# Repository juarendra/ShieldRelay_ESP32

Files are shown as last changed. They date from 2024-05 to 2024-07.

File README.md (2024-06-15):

# ShieldRelay_ESP32
Relay Shield for ESP32 , Nodemcu V2 Amica or Nodemcu V3 Lolin. In board there are 5 Relay and 3 type of Relay, first is 30A Relay Coil, second is 10 A Relay Coil and third is SSR 2A. And there are full extend header of Microcontroller. the power using Stepdown LM2596 with output 5V 3A and Input 5-30VDC. 

## Spesification ShieldRelay_ESP32
- Input Power 5-30VDC and stepdown to 5VDC
- PTC Fuse
- INPUT HEADER
- VCC HEADER
- VCC Selector 3v3 or 5V
- Supported ESP32 DEV KIT, NODEMCU V2 or V3
- Pin Header GPIO with Servo Formated
- 1 x 30A Relay Coil
- 2 x 10A Relay Couil
- 2 x 2A SSR

# Privew Hardware ShieldRelay_ESP32
<p align="center">
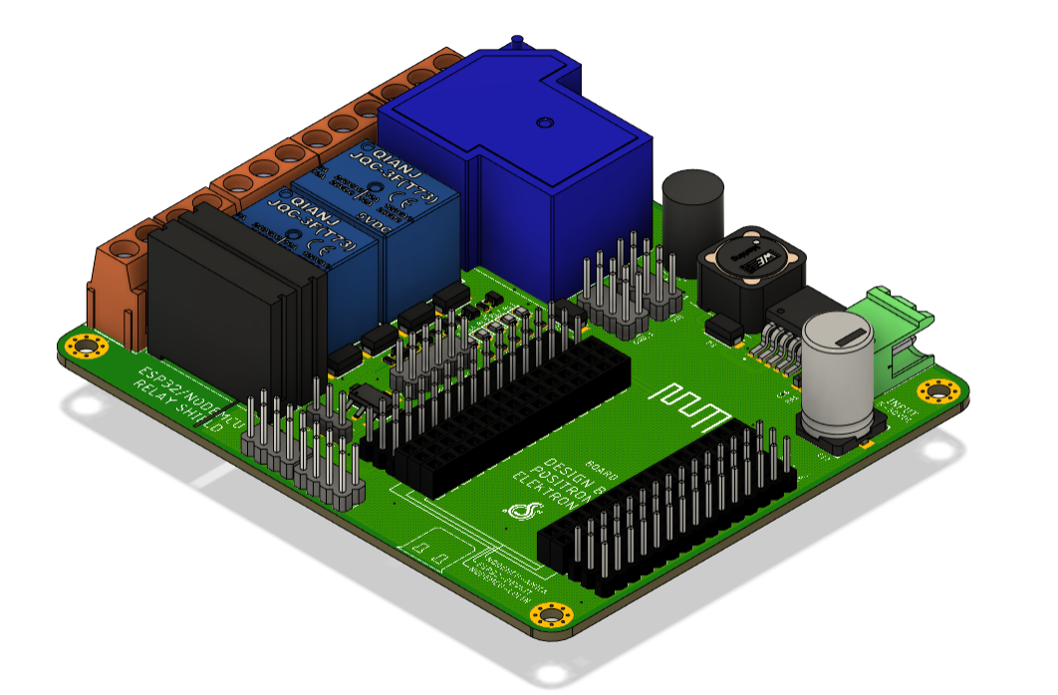
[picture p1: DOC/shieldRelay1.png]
  
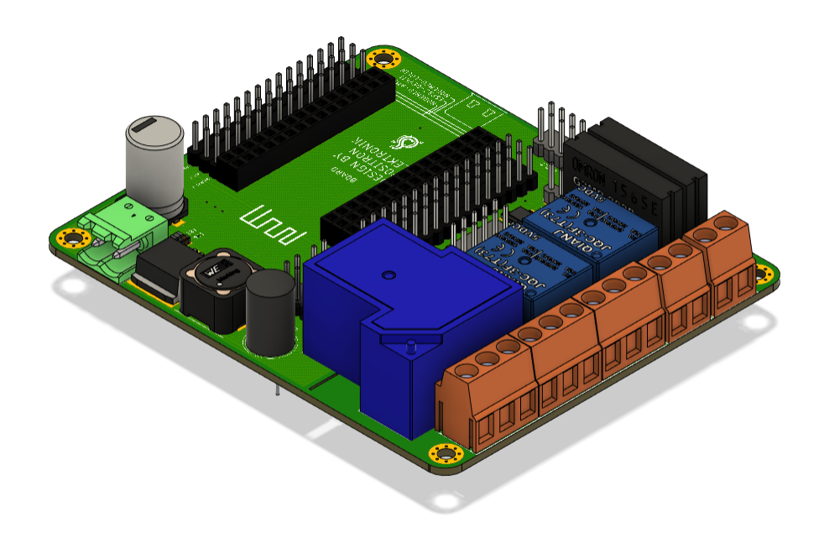
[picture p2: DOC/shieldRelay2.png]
  
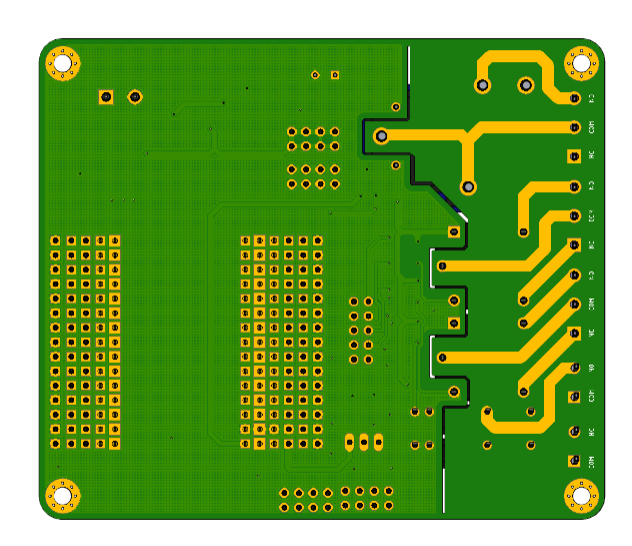
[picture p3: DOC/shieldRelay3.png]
  
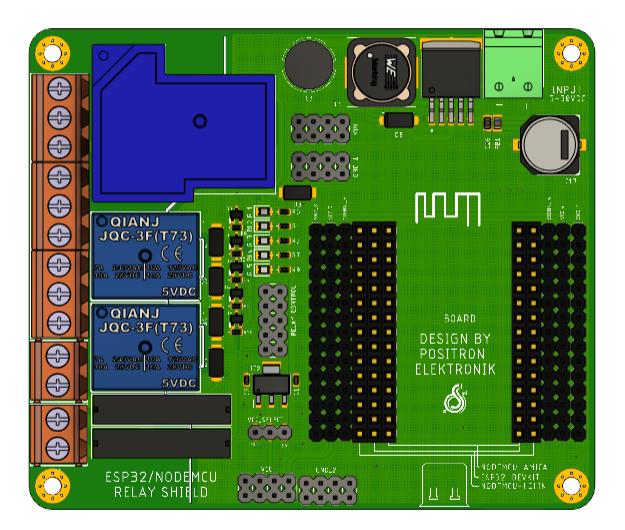
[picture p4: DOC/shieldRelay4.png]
  
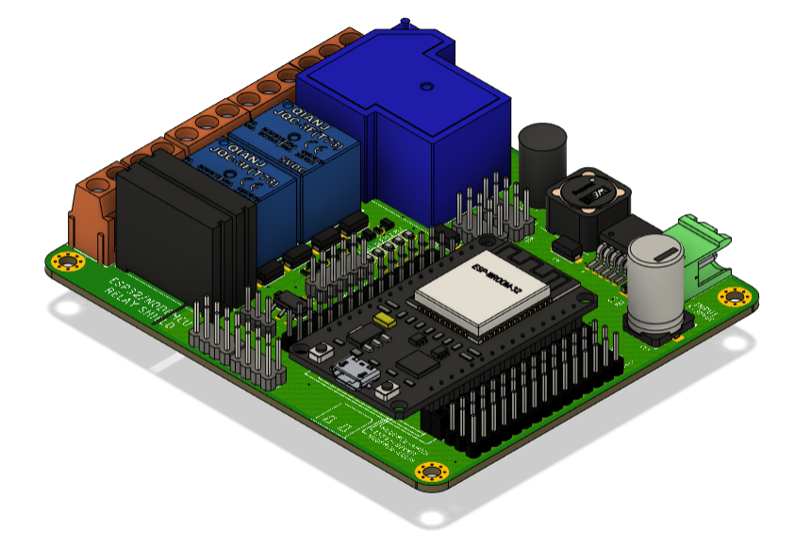
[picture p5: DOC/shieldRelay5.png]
  
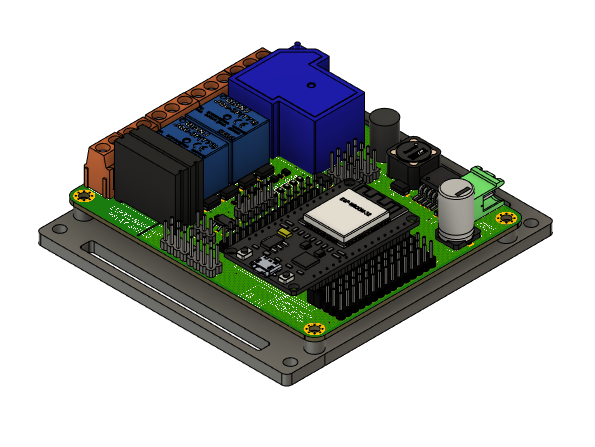
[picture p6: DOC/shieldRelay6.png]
  
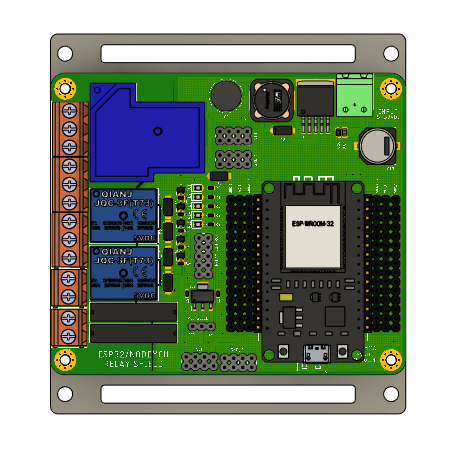
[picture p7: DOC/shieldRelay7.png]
  
</p>

# Documentation 
- [Dimension](https://github.com/juarendra/ShieldRelay_ESP32/blob/main/HARDWARE/dimension_shield_esp32.pdf)
- [BOM](https://github.com/juarendra/ShieldRelay_ESP32/blob/main/DOC/BOM_shieldRelay.csv)

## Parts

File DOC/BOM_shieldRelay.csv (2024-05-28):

Qty | Value | Device | Package | Parts | Description | ARROW_PART_NUMBER | ARROW_PRICE-STOCK | DESCRIPTION | DIGIKEY_PARTNUMBER | DIGIKEY_PRICE-STOCK | ESP32-DEVKITV1 | HEIGHT | MANUFACTURER_NAME | MANUFACTURER_PART_NUMBER | MOUSER_PART_NUMBER | MOUSER_PRICE-STOCK | POPULARITY
9 |  | PINHD-1X15 | 1X15 | GND_3, GND_4, JP11, JP12, JP13, SIGNAL_3, SIGNAL_4, VCC_3, VCC_4 | PIN HEADER |  |  |  |  |  |  |  |  |  |  |  | 4
1 |  | PINHD-1X3 | 1X03 | VCC_SELECT | PIN HEADER |  |  |  |  |  |  |  |  |  |  |  | 92
4 |  | PINHD-2X4 | 2X04 | GND_1, GND_2, VCC, VIN | PIN HEADER |  |  |  |  |  |  |  |  |  |  |  | 47
1 |  | PINHD-2X5 | 2X05 | RELAY_CONTROL | PIN HEADER |  |  |  |  |  |  |  |  |  |  |  | 35
2 | 0.1uf | KGM15BR71E104KT | CAPC1608X95N | C1, C2 | 0603 25 V X7R 100nF +/-10% |  |  | 0603 25 V X7R 100nF +/-10% |  |  |  | 0.95mm | Kyocera AVX | KGM15BR71E104KT | 581-KGM15BR71E104KT | https://www.mouser.co.uk/ProductDetail/KYOCERA-AVX/KGM15BR71E104KT?qs=Jm2GQyTW%2FbiCo%2Fby4Q068Q%3D%3D
5 | 150080SS75000 | 150080SS75000 | LEDC2012X80N | RL1, RL2, RL3, RL4, RL5 | Wurth Elektronik 150080SS75000, WL-SMCW Series Red LED, 630 nm, 2012 (0805) Clear, Rectangle Lens SMD Package |  |  | Wurth Elektronik 150080SS75000, WL-SMCW Series Red LED, 630 nm, 2012 (0805) Clear, Rectangle Lens SMD Package | 732-4985-1-ND | https://www.digikey.com/product-detail/en/w%C3%BCrth-elektronik/150080SS75000/732-4985-1-ND/4489919 |  | 0.8mm | Wurth Elektronik | 150080SS75000 | 710-150080SS75000 | https://www.mouser.co.uk/ProductDetail/Wurth-Elektronik/150080SS75000?qs=LlUlMxKIyB2zzpiaOzrUdw%3D%3D
2 | 1716080000 | 1716080000 | 1716080000 | RELAY4, RELAY5 | Printed circuit board terminals, 5.08 mm, Number of poles: 2, 90, Solder pin length: 3.5 mm, tinned, orange, Clamping yoke connection, Clamping range, max. [rated connection]: 2.5 mm, Box |  |  | Printed circuit board terminals, 5.08 mm, Number of poles: 2, 90, Solder pin length: 3.5 mm, tinned, orange, Clamping yoke connection, Clamping range, max. [rated connection]: 2.5 mm, Box |  |  |  | 13.8mm | Weidmuller | 1716080000 | 470-1716080000 | https://www.mouser.co.uk/ProductDetail/Weidmuller/1716080000?qs=BTG2th8YmhQnu8ZhPH6LgQ%3D%3D
3 | 1716090000 | 1716090000 | SHDR3W95P0X508_1X3_1524X1000X1 | RELAY1, RELAY2, RELAY3 | Printed circuit board terminals, 5.08 mm, Number of poles: 3, 90, Solder pin length: 3.5 mm, tinned, orange, Clamping yoke connection, Clamping range, max. [rated connection]: 2.5 mm, Box |  |  | Printed circuit board terminals, 5.08 mm, Number of poles: 3, 90, Solder pin length: 3.5 mm, tinned, orange, Clamping yoke connection, Clamping range, max. [rated connection]: 2.5 mm, Box |  |  |  | 13.8mm | Weidmuller | 1716090000 | 470-1716090000 | https://www.mouser.co.uk/ProductDetail/Weidmuller/1716090000?qs=BTG2th8YmhRwtiTHzuCKAQ%3D%3D
1 | 1759017 | 1759017 | SHDRRA2W103P0X508_1X2_1016X120 | INPUT | PCB header, nominal cross section: 2.5 mm?, color: green, nominal current: 12 A, rated voltage (III/2): 320 V, contact surface: Tin, type of contact: Male connector, Number of potentials: 2, Number of rows: 1, Number of positions per row: 2, number of connections: 2, product range: MSTB 2,5/..-G, pitch: 5.08 mm, mounting: Wave soldering, pin layout: Linear pinning, solder pin [P]: 3.5 mm, Stecksystem: CLASSIC COMBICON, Locking: without, type of packaging: packed in cardboard |  |  | PCB header, nominal cross section: 2.5 mm?, color: green, nominal current: 12 A, rated voltage (III/2): 320 V, contact surface: Tin, type of contact: Male connector, Number of potentials: 2, Number of rows: 1, Number of positions per row: 2, number of connections: 2, product range: MSTB 2,5/..-G, pitch: 5.08 mm, mounting: Wave soldering, pin layout: Linear pinning, solder pin [P]: 3.5 mm, Stecksystem: CLASSIC COMBICON, Locking: without, type of packaging: packed in cardboard |  |  |  | 8.72mm | Phoenix Contact | 1759017 | 651-1759017 | https://www.mouser.co.uk/ProductDetail/Phoenix-Contact/1759017?qs=BYlwlsDsB%2FoOYIHqYLxOcg%3D%3D
10 | 1k | ERA-3AED102V | ERA3AEB101V | R1, R2, R3, R4, R5, R6, R7, R8, R9, R10 | Thin Film Resistors - SMD 0603 1000ohms 25ppm 0.5% AEC-Q200 |  |  | Thin Film Resistors - SMD 0603 1000ohms 25ppm 0.5% AEC-Q200 |  |  |  | 0.55mm | Panasonic | ERA-3AED102V | 667-ERA-3AED102V | https://www.mouser.co.uk/ProductDetail/Panasonic/ERA-3AED102V?qs=yocZuyCaXdNrh6oeFjCchg%3D%3D
1 | 2.2uf | KAF21KR71H225KU | CAPC2012X140N | C16 | Multilayer Ceramic Capacitors MLCC - SMD/SMT 50V 2.2uF X7R 0805 10% AEC-Q200 FLEXITERM |  |  | Multilayer Ceramic Capacitors MLCC - SMD/SMT 50V 2.2uF X7R 0805 10% AEC-Q200 FLEXITERM |  |  |  | 1.4mm | Kyocera AVX | KAF21KR71H225KU | 581-KAF21KR71H225KU | https://www.mouser.co.uk/ProductDetail/KYOCERA-AVX/KAF21KR71H225KU?qs=Jm2GQyTW%2FbjwwNTLmtUMeQ%3D%3D
1 | 220uf 25V | MAL203836221E3 | CAPPRD350W60D850H1250 | C3 | VISHAY - MAL203836221E3 - CAP, 220F, 25V, 20% |  |  | VISHAY - MAL203836221E3 - CAP, 220F, 25V, 20% |  |  |  | 12.5mm | Vishay | MAL203836221E3 | 594-MAL203836221E3 | https://www.mouser.co.uk/ProductDetail/Vishay-BC-Components/MAL203836221E3?qs=G99oyVYclWUIwcN6B3qC5w%3D%3D
1 | 33uh 12x12 | 744770133 | WE-PD_1260/1245/1280/121054 | L1 | Wurth WE-PD Series Shielded Wire-wound SMD Inductor with a Ferrite Core, 33 uH +/-20% 3.6A Idc |  |  | Wurth WE-PD Series Shielded Wire-wound SMD Inductor with a Ferrite Core, 33 uH +/-20% 3.6A Idc |  |  |  | mm | Wurth Elektronik | 744770133 | 710-744770133 | https://www.mouser.co.uk/ProductDetail/Wurth-Elektronik/744770133?qs=E%2F%2FhvbtCqpPKkGJl8TxFXw%3D%3D
4 | 3MM_HOLE | 3MM_HOLE | 3MM_HOLE | H1, H2, H3, H4 | Cool looking 3mm hole with ground connection
1 | 680uf | EEH-ZU1V681UP | EEHZS1H221P | C17 | Conductive Polymer Hybrid Aluminum Electrolytic Capacitor |  |  | Conductive Polymer Hybrid Aluminum Electrolytic Capacitor |  |  |  | 10.5mm | Panasonic | EEH-ZU1V681UP | 667-EEH-ZU1V681UP | https://www.mouser.co.uk/ProductDetail/Panasonic/EEH-ZU1V681UP?qs=HoCaDK9Nz5elLexP3akqig%3D%3D
1 | B340A-13-F | B340A-13-F | DIOM5226X240N | D8 | Schottky Diode 3A 40V 0.5Vf SMA Diodes Inc B340A-13-F, SMT Schottky Diode, 40V 3A, 2-Pin DO-214AC |  |  | Schottky Diode 3A 40V 0.5Vf SMA Diodes Inc B340A-13-F, SMT Schottky Diode, 40V 3A, 2-Pin DO-214AC |  |  |  | 2.4mm | Diodes Incorporated | B340A-13-F | 621-B340A-F | https://www.mouser.co.uk/ProductDetail/Diodes-Incorporated/B340A-13-F?qs=aLaTXeBcTP9fj%2FYKVo6Q1A%3D%3D
1 | BLM21PG221SN1D | BLM21PG221SN1D | BEADC2012X105N | FB1 | Murata Ferrite Bead (Chip Ferrite Bead), 2 x 1.25 x 0.85mm |  |  | Murata Ferrite Bead (Chip Ferrite Bead), 2 x 1.25 x 0.85mm |  |  |  | 1.05mm | Murata Electronics | BLM21PG221SN1D | 81-BLM21P221SG | https://www.mouser.co.uk/ProductDetail/Murata-Electronics/BLM21PG221SN1D?qs=N%2FLoXOA9PTJ4i6RHFrsqmw%3D%3D
1 | ESP32DEVKITV1 | ESP32DEVKITV1 | ESP32-DEVKITV1 | BOARD | https://github.com/shridattdudhat
5 | FM4004-W | FM4004-W | DIONM5025X231N | D1, D2, D3, D4, D5 | Rectifiers 1N4004 1A 400V |  |  | Rectifiers 1N4004 1A 400V |  |  |  | 2.31mm | Rectron | FM4004-W | 583-FM4004 | https://www.mouser.co.uk/ProductDetail/Rectron/FM4004-W?qs=Iw9Ubr57Px3IHNH1bE4l9w%3D%3D
2 | G3MB-202PL-DC5 | G3MB-202PL-DC5 | G3MB202PLDC5 | K3, K5 | Solid State Relays - PCB Mount 5VDC/100-240VAC 2A |  |  | Solid State Relays - PCB Mount 5VDC/100-240VAC 2A |  |  |  | 20.5mm | Omron Electronics | G3MB-202PL-DC5 | 653-G3MB-202PL-DC5 | https://www.mouser.co.uk/ProductDetail/Omron-Automation-and-Safety/G3MB-202PL-DC5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
1 | LM1117MPX-33NOPB | LM1117MPX-33NOPB | SOT230P700X180-4N | IC2 | LDO Voltage Regulators 800-mA 15-V linear voltage regulator 800-mA 15-V linear voltage regulator |  |  | LDO Voltage Regulators 800-mA 15-V linear voltage regulator 800-mA 15-V linear voltage regulator |  |  |  | 1.8mm | onsemi | LM1117MPX-33NOPB | 863-LM1117MPX-33NOPB | https://www.mouser.co.uk/ProductDetail/onsemi/LM1117MPX-33NOPB?qs=DPoM0jnrROUIbzbQHFmeig%3D%3D
1 | LM2596SX-5.0_NOPB | LM2596SX-5.0_NOPB | KTT0005B | IC1 | SIMPLE SWITCHER&#174; 4.5V to 40V, 3A Low Component Count Step-Down Regulator |  |  | SIMPLE SWITCHER&#174 | 4.5V to 40V, 3A Low Component Count Step-Down Regulator |  |  |  | mm | Texas Instruments | LM2596SX-5.0/NOPB | 926-LM2596SX-5.0NOPB | https://www.mouser.co.uk/ProductDetail/Texas-Instruments/LM2596SX-5.0-NOPB?qs=X1J7HmVL2ZGZ5T4VcWdmNw%3D%3D
5 | MMST2222A-7-F | MMST2222A-7-F | SOT65P210X110-3N | Q1, Q2, Q3, Q4, Q5 | Bipolar (BJT) Transistor NPN 40 V 600 mA 300MHz 200 mW Surface Mount SOT-323 |  |  | Bipolar (BJT) Transistor NPN 40 V 600 mA 300MHz 200 mW Surface Mount SOT-323 |  |  |  | 1.1mm | Diodes Incorporated | MMST2222A-7-F | 621-MMST2222A-F | https://www.mouser.co.uk/ProductDetail/Diodes-Incorporated/MMST2222A-7-F?qs=B0AElM0L7fPu4CagNNXsRQ%3D%3D
1 | SLA-05VDC-SL-C | SLA-05VDC-SL-C | SLA05VDCSLC | K1 | Relays General Purpose Non Latching 5VDC SPDT 30A (250VAC) Max Plugin RoHS |  |  | Relays General Purpose Non Latching 5VDC SPDT 30A (250VAC) Max Plugin RoHS |  |  |  | 20.4mm | Songle Relay | SLA-05VDC-SL-C
2 | SRD-05VDC-SL-C | SRD-05VDC-SL-C | SRD05VDCSLC | K2, K6 | SRD-05VDC-SL-C; RELAY ISO9002 1. MAIN FEATURES Switching capacity available by 10A in spite of small size design for highdensity P.C. board mounting technique. U |  |  | SRD-05VDC-SL-C | RELAY ISO9002 1. MAIN FEATURES Switching capacity available by 10A in spite of small size design for highdensity P.C. board mounting technique. U |  |  |  | 15.8mm | EAGLE | SRD-05VDC-SL-C

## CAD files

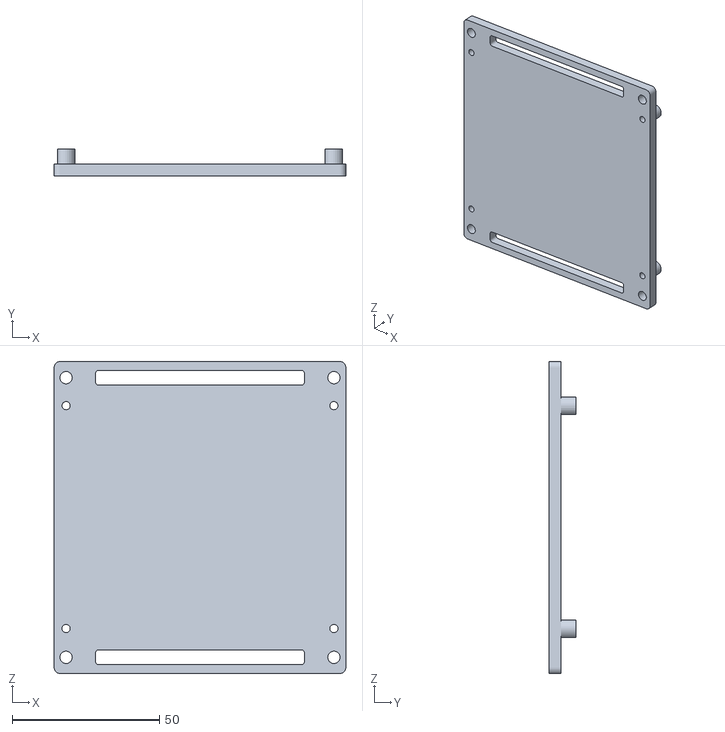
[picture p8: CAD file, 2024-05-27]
HARDWARE/PLATE/shieldRelayPlate.stl
99.1 x 9.00 x 105.9

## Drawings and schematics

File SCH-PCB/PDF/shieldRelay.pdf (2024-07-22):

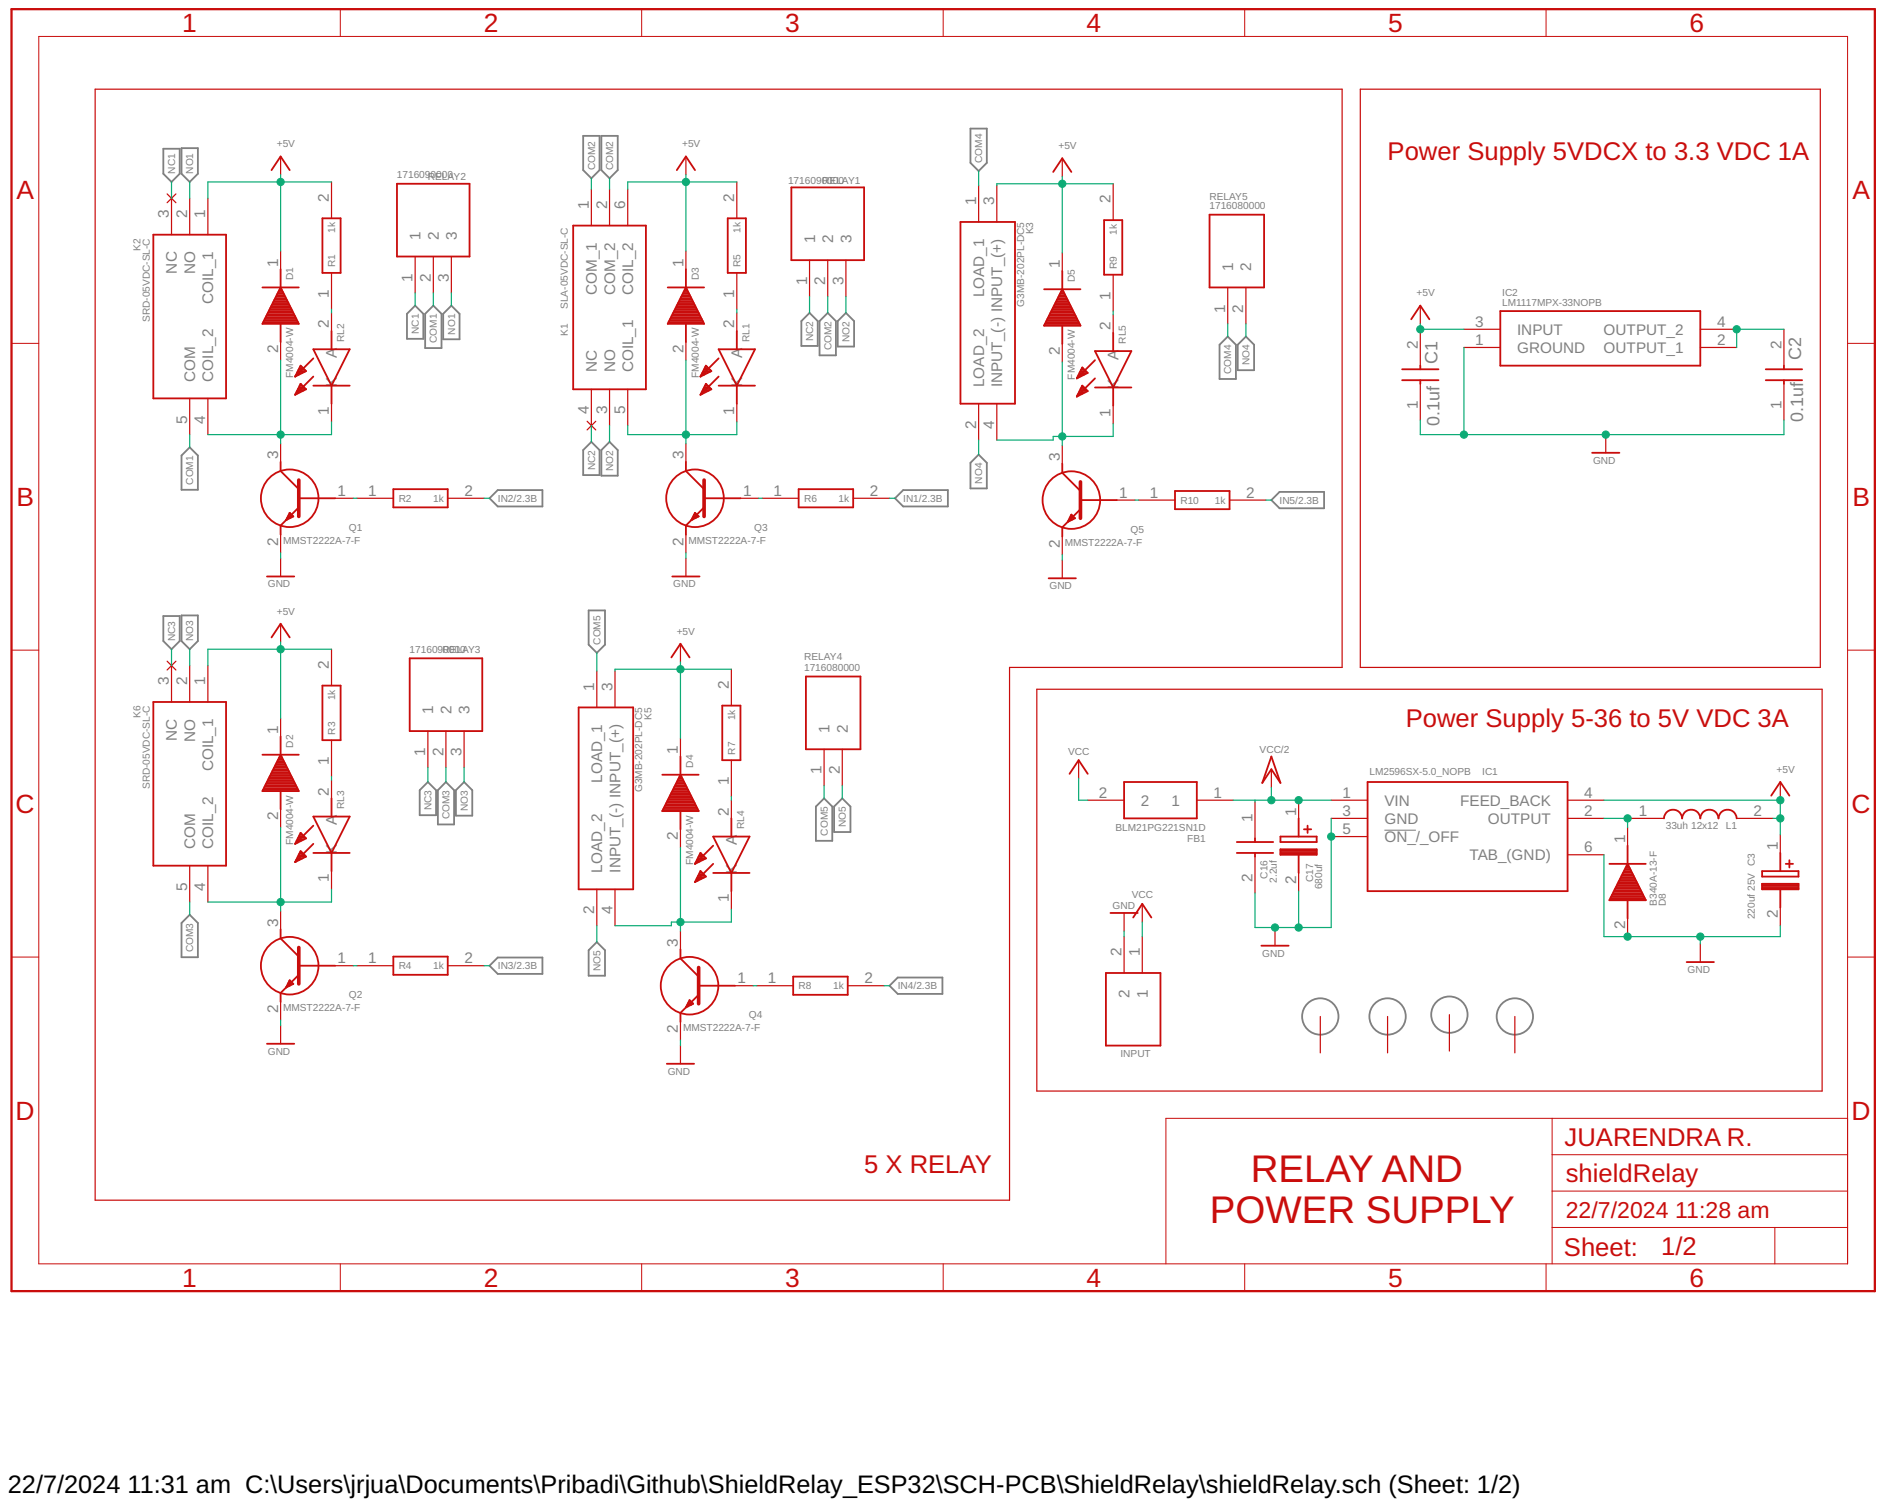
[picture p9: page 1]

Power Supply 5VDCX to 3.3 VDC 1A

NO4 Power Supply 5-36 to 5V VDC 3A

RELAY AND POWER SUPPLY

22/7/2024 11:31 am C:\Users\jrjua\Documents\Pribadi\Github\ShieldRelay_ESP32\SCH-PCB\ShieldRelay\shieldRelay.sch (Sheet: 1/2)

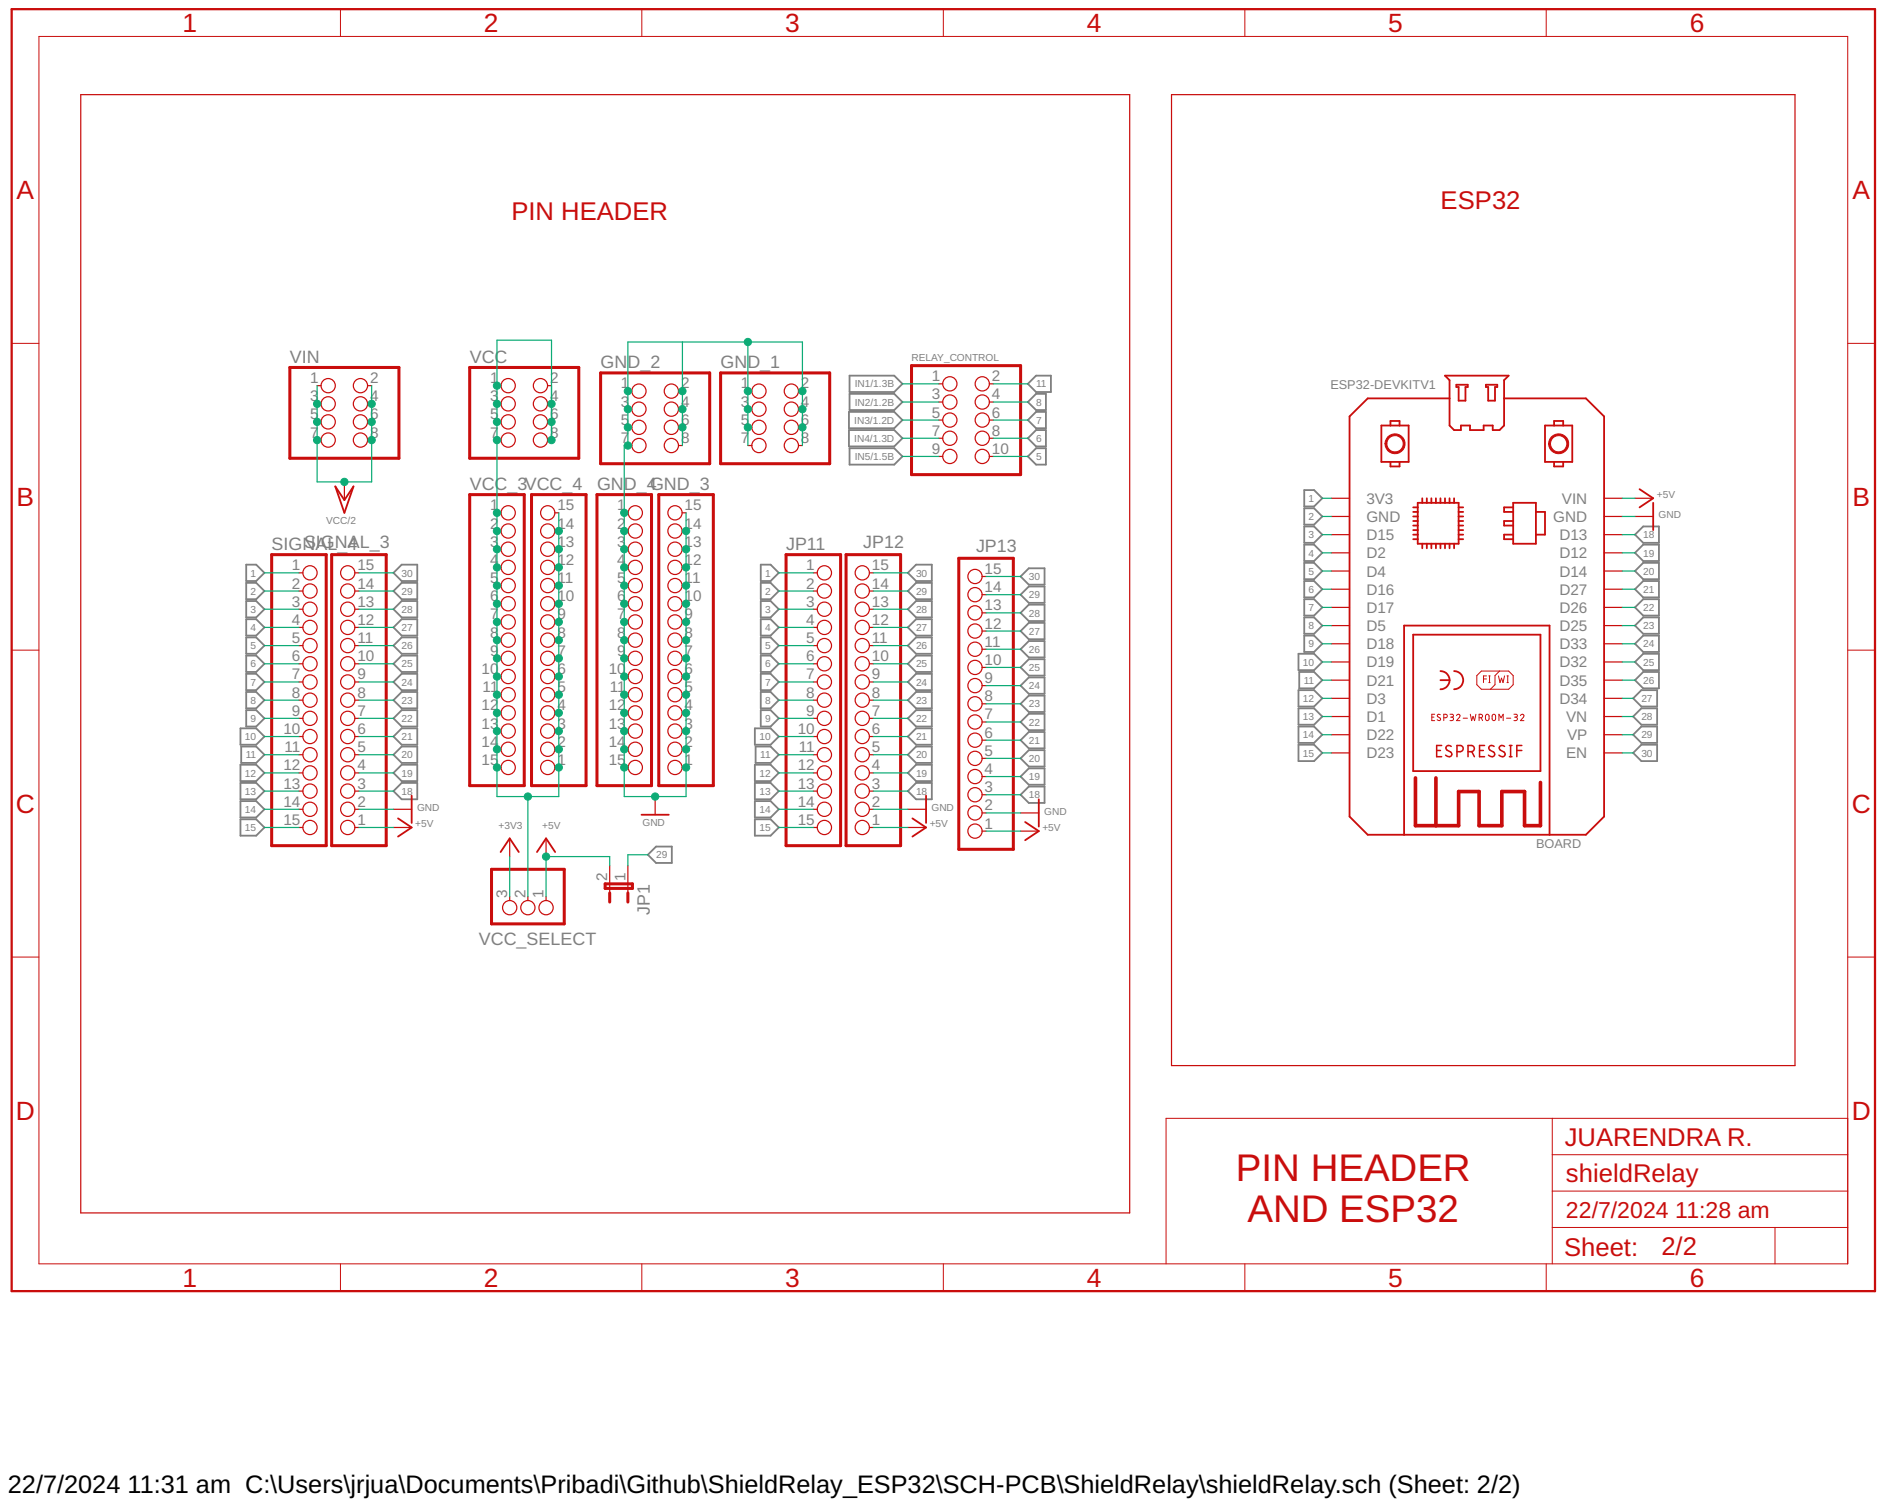
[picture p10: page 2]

22/7/2024 11:31 am C:\Users\jrjua\Documents\Pribadi\Github\ShieldRelay_ESP32\SCH-PCB\ShieldRelay\shieldRelay.sch (Sheet: 2/2)

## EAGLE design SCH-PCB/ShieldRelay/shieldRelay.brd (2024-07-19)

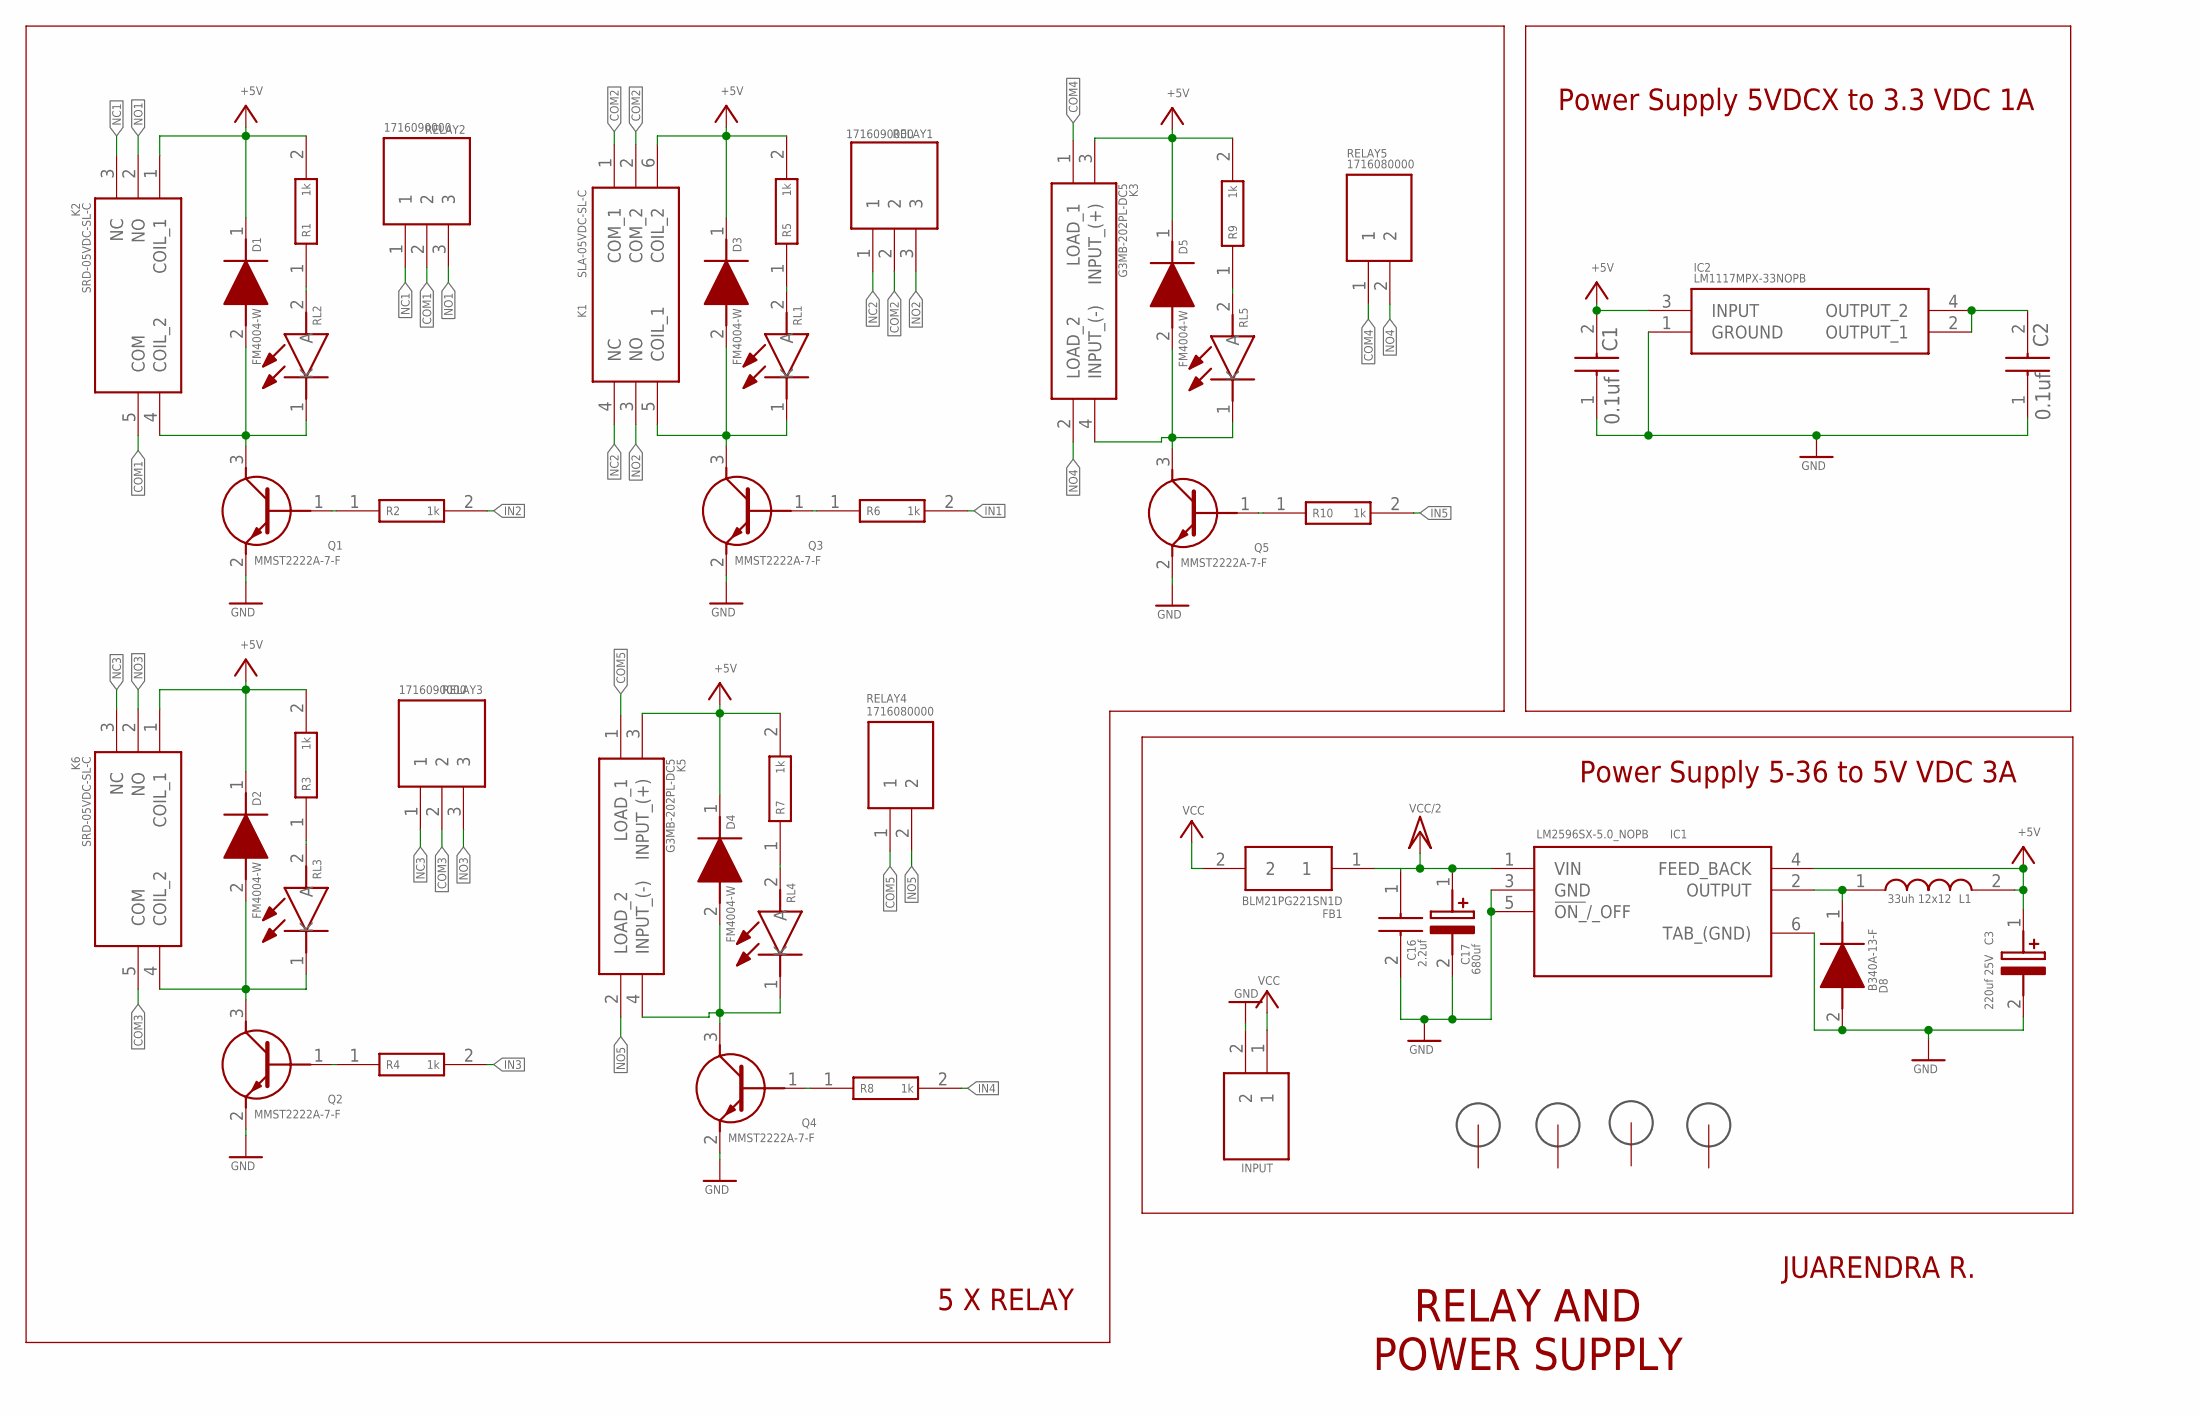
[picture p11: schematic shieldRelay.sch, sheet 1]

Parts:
C1, C2: 0.1uf; CAPC1608X95N
C3: 220uf 25V; CAPPRD350W60D850H1250
C16: 2.2uf; CAPC2012X140N
C17: 680uf; EEHZS1H221P
D1, D2, D3, D4, D5: FM4004-W; DIONM5025X231N
D8: B340A-13-F; DIOM5226X240N
FB1: BLM21PG221SN1D; BEADC2012X105N
H1, H2, H3, H4: 3MM_HOLE
IC1: LM2596SX-5.0_NOPB; KTT0005B
IC2: LM1117MPX-33NOPB; SOT230P700X180-4N
INPUT: 1759017; SHDRRA2W103P0X508_1X2_1016X120
K1: SLA-05VDC-SL-C; SLA05VDCSLC
K2, K6: SRD-05VDC-SL-C; SRD05VDCSLC
K3, K5: G3MB-202PL-DC5; G3MB202PLDC5
L1: 33uh 12x12; WE-PD_1260/1245/1280/121054
Q1, Q2, Q3, Q4, Q5: MMST2222A-7-F; SOT65P210X110-3N
R1, R2, R3, R4, R5, R6, R7, R8, R9, R10: 1k; ERA3AEB101V
RELAY1, RELAY2, RELAY3: 1716090000; SHDR3W95P0X508_1X3_1524X1000X1
RELAY4, RELAY5: 1716080000
RL1, RL2, RL3, RL4, RL5: 150080SS75000; LEDC2012X80N

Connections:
+5V: C1.2, C3.1 (+), D1.1 (K), D2.1 (K), D3.1 (K), D4.1 (K), D5.1 (K), IC1.4 (FEED_BACK), IC2.3 (INPUT), K1.6 (COIL_2), K2.1 (COIL_1), K3.3 (INPUT_(+)), K5.3 (INPUT_(+)), K6.1 (COIL_1), L1.2, R1.2, R3.2, R5.2, R7.2, R9.2; also elsewhere on the board
COM1: K2.5 (COM), RELAY2.2
COM2: K1.1 (COM_1), K1.2 (COM_2), RELAY1.2
COM3: K6.5 (COM), RELAY3.2
COM4: K3.1 (LOAD_1), RELAY5.1
COM5: K5.1 (LOAD_1), RELAY4.1
GND: C1.1, C2.1, C3.2 (-), C16.2, C17.2 (-), D8.2 (A), IC1.3 (GND), IC1.5 (!ON_!/_OFF), IC1.6 (TAB_(GND)), IC2.1 (GROUND), INPUT.2, Q1.2 (E), Q2.2 (E), Q3.2 (E), Q4.2 (E), Q5.2 (E); also elsewhere on the board
IN1: R6.2; also elsewhere on the board
IN2: R2.2; also elsewhere on the board
IN3: R4.2; also elsewhere on the board
IN4: R8.2; also elsewhere on the board
IN5: R10.2; also elsewhere on the board
unnamed: R3.1, RL3.2 (A)
unnamed: R1.1, RL2.2 (A)
unnamed: D1.2 (A), K2.4 (COIL_2), Q1.3 (C), RL2.1 (K)
unnamed: Q1.1 (B), R2.1
unnamed: D2.2 (A), K6.4 (COIL_2), Q2.3 (C), RL3.1 (K)
unnamed: Q2.1 (B), R4.1
unnamed: R5.1, RL1.2 (A)
unnamed: D3.2 (A), K1.5 (COIL_1), Q3.3 (C), RL1.1 (K)
unnamed: Q3.1 (B), R6.1
unnamed: R7.1, RL4.2 (A)
unnamed: D4.2 (A), K5.4 (INPUT_(-)), Q4.3 (C), RL4.1 (K)
unnamed: Q4.1 (B), R8.1
unnamed: R9.1, RL5.2 (A)
unnamed: D5.2 (A), K3.4 (INPUT_(-)), Q5.3 (C), RL5.1 (K)
unnamed: Q5.1 (B), R10.1
unnamed: D8.1 (K), IC1.2 (OUTPUT), L1.1
unnamed: C2.2, IC2.2 (OUTPUT_1), IC2.4 (OUTPUT_2)
NC1: K2.3 (NC), RELAY2.1
NC2: K1.4 (NC), RELAY1.1
NC3: K6.3 (NC), RELAY3.1
NO1: K2.2 (NO), RELAY2.3
NO2: K1.3 (NO), RELAY1.3
NO3: K6.2 (NO), RELAY3.3
NO4: K3.2 (LOAD_2), RELAY5.2
NO5: K5.2 (LOAD_2), RELAY4.2
VCC: FB1.2, INPUT.1
VCC/2: C16.1, C17.1 (+), FB1.1, IC1.1 (VIN); also elsewhere on the board

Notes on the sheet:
Power Supply 5-36 to 5V VDC 3A
5 X RELAY
Power Supply 5VDCX to 3.3 VDC 1A
RELAY AND POWER SUPPLY
JUARENDRA R.

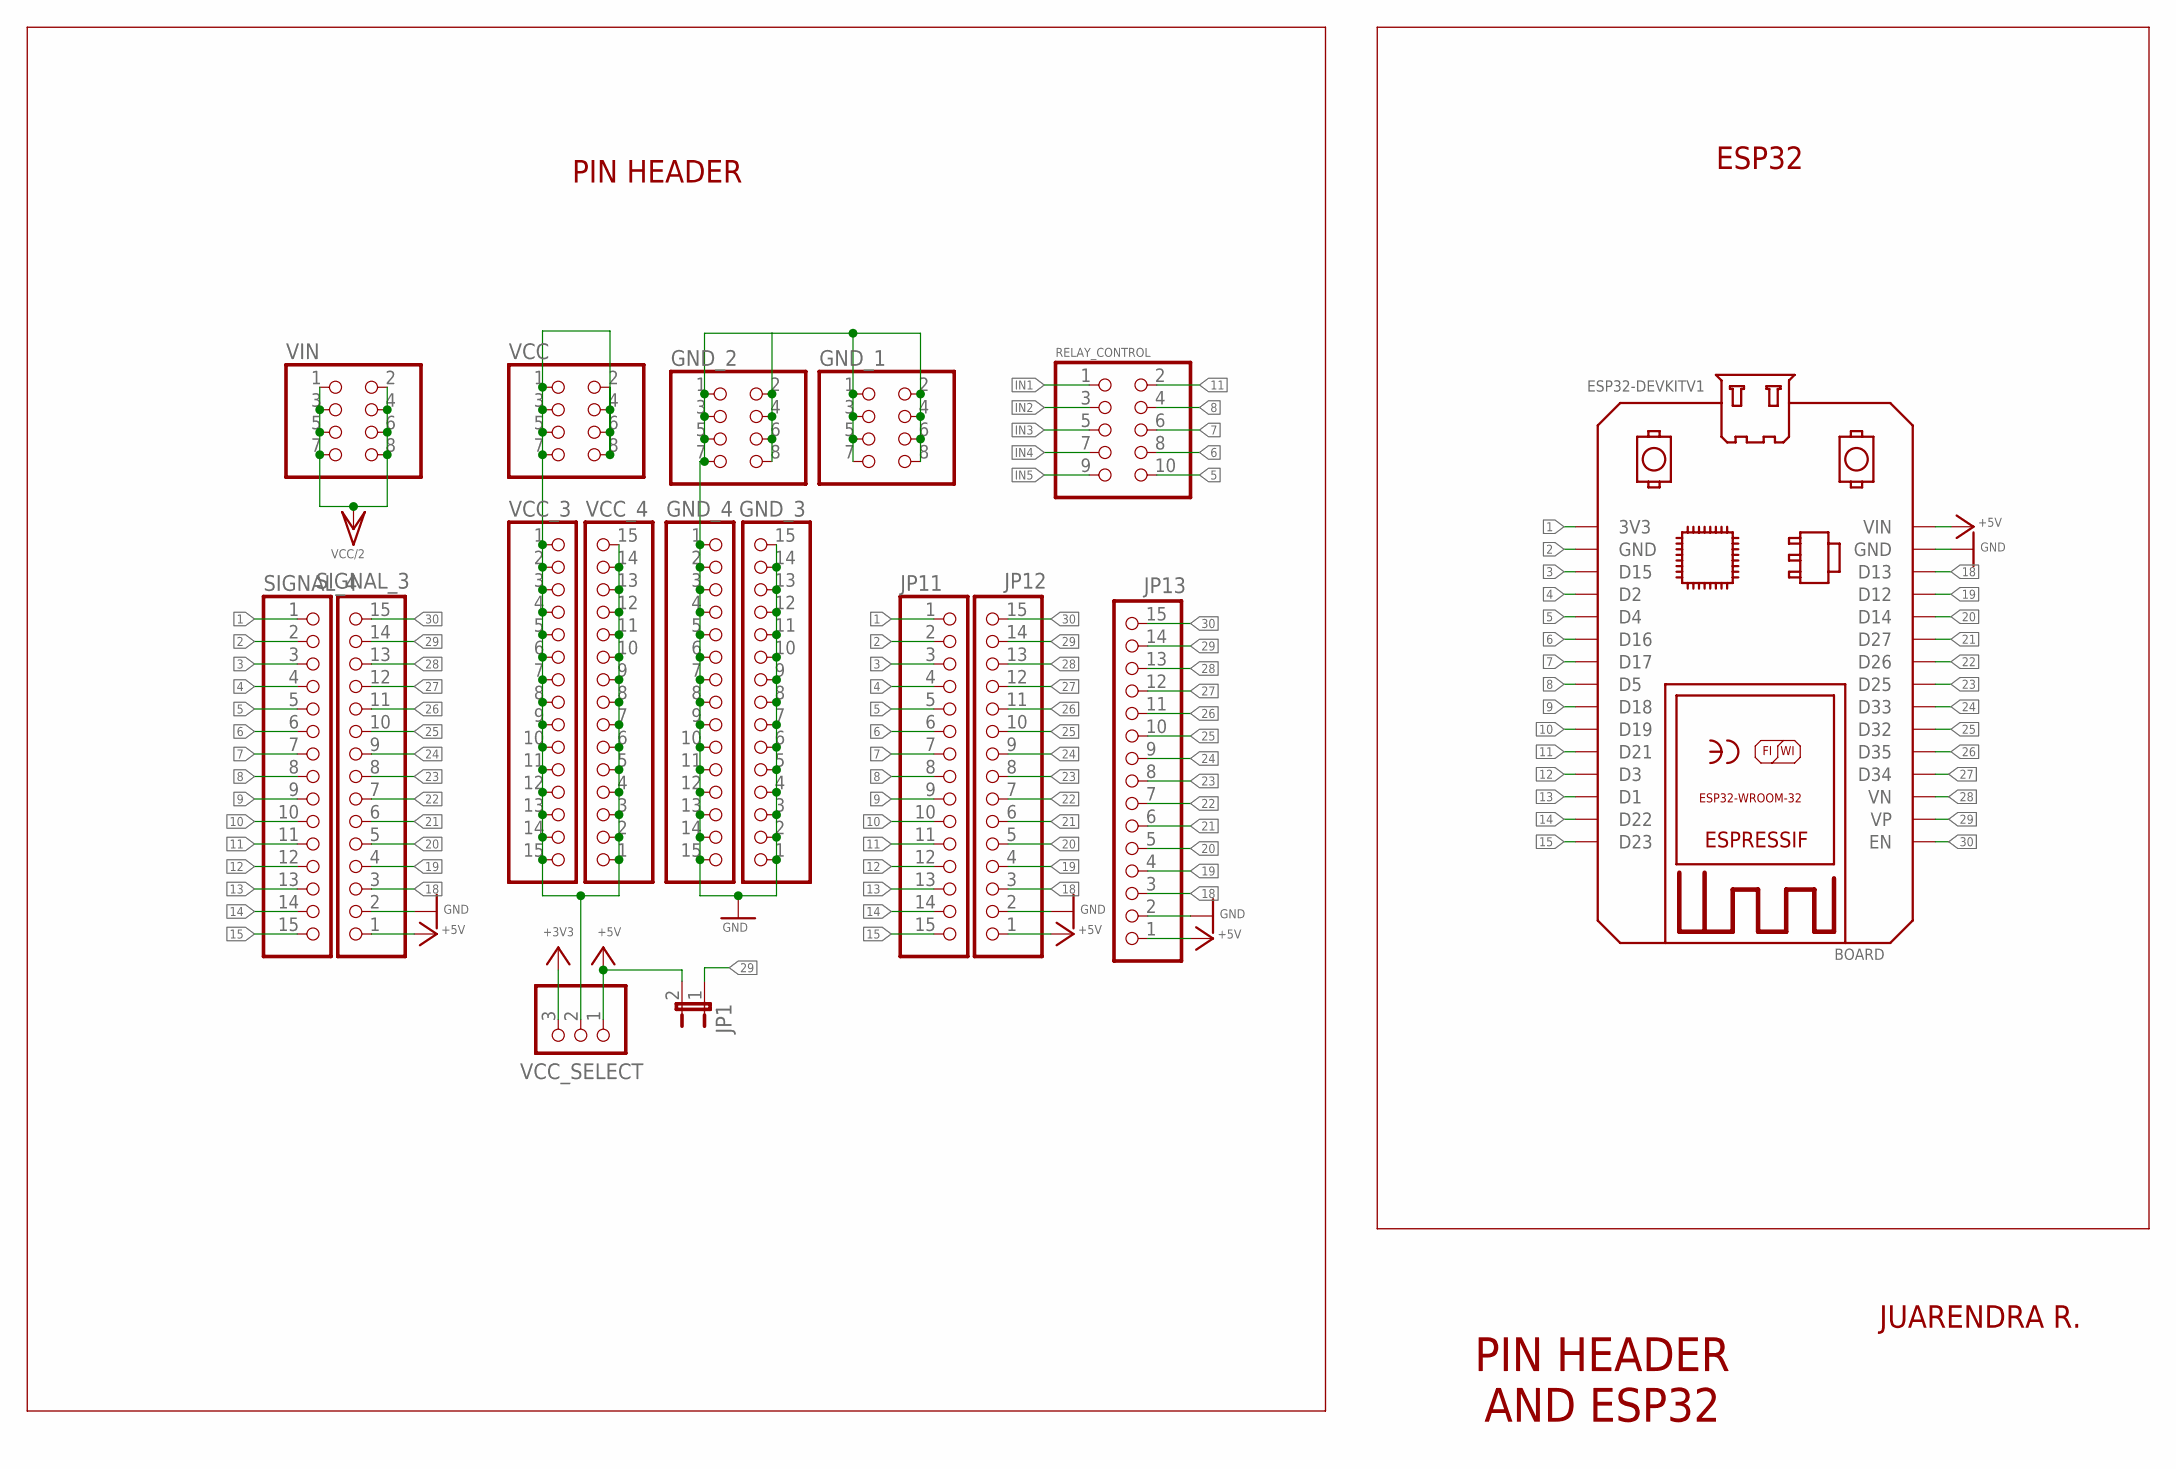
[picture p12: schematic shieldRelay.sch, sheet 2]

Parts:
BOARD: ESP32DEVKITV1; ESP32-DEVKITV1
GND_1, GND_2: PINHD-2X4; 2X04
GND_3, GND_4: PINHD-1X15; 1X15
JP1: JP1E; JP1
JP11, JP12, JP13: PINHD-1X15; 1X15
RELAY_CONTROL: PINHD-2X5; 2X05
SIGNAL_3, SIGNAL_4: PINHD-1X15; 1X15
VCC: PINHD-2X4; 2X04
VCC_3, VCC_4: PINHD-1X15; 1X15
VCC_SELECT: PINHD-1X3; 1X03
VIN: PINHD-2X4; 2X04

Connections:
1: BOARD.3V3, JP11.1, SIGNAL_4.1
2: BOARD.GND@1 (GND), JP11.2, SIGNAL_4.2
3: BOARD.D15, JP11.3, SIGNAL_4.3
4: BOARD.D2, JP11.4, SIGNAL_4.4
5: BOARD.D4, JP11.5, RELAY_CONTROL.10, SIGNAL_4.5
6: BOARD.D16, JP11.6, RELAY_CONTROL.8, SIGNAL_4.6
7: BOARD.D17, JP11.7, RELAY_CONTROL.6, SIGNAL_4.7
8: BOARD.D5, JP11.8, RELAY_CONTROL.4, SIGNAL_4.8
9: BOARD.D18, JP11.9, SIGNAL_4.9
10: BOARD.D19, JP11.10, SIGNAL_4.10
11: BOARD.D21, JP11.11, RELAY_CONTROL.2, SIGNAL_4.11
12: BOARD.D3, JP11.12, SIGNAL_4.12
13: BOARD.D1, JP11.13, SIGNAL_4.13
14: BOARD.D22, JP11.14, SIGNAL_4.14
15: BOARD.D23, JP11.15, SIGNAL_4.15
18: BOARD.D13, JP12.3, JP13.3, SIGNAL_3.3
19: BOARD.D12, JP12.4, JP13.4, SIGNAL_3.4
20: BOARD.D14, JP12.5, JP13.5, SIGNAL_3.5
21: BOARD.D27, JP12.6, JP13.6, SIGNAL_3.6
22: BOARD.D26, JP12.7, JP13.7, SIGNAL_3.7
23: BOARD.D25, JP12.8, JP13.8, SIGNAL_3.8
24: BOARD.D33, JP12.9, JP13.9, SIGNAL_3.9
25: BOARD.D32, JP12.10, JP13.10, SIGNAL_3.10
26: BOARD.D35, JP12.11, JP13.11, SIGNAL_3.11
27: BOARD.D34, JP12.12, JP13.12, SIGNAL_3.12
28: BOARD.VN, JP12.13, JP13.13, SIGNAL_3.13
29: BOARD.VP, JP1.1, JP12.14, JP13.14, SIGNAL_3.14
30: BOARD.EN, JP12.15, JP13.15, SIGNAL_3.15
+3V3: VCC_SELECT.3
+5V: BOARD.VIN, JP1.2, JP12.1, JP13.1, SIGNAL_3.1, VCC_SELECT.1; also elsewhere on the board
GND: BOARD.GND, GND_1.1, GND_1.2, GND_1.3, GND_1.4, GND_1.5, GND_1.6, GND_1.7, GND_1.8, GND_2.1, GND_2.2, GND_2.3, GND_2.4, GND_2.5, GND_2.6, GND_2.7, GND_2.8, GND_3.1, GND_3.2, GND_3.3, GND_3.4, GND_3.5, GND_3.6, GND_3.7, GND_3.8, GND_3.9, GND_3.10, GND_3.11, GND_3.12, GND_3.13, GND_3.14, GND_3.15, GND_4.1, GND_4.2, GND_4.3, GND_4.4, GND_4.5, GND_4.6, GND_4.7, GND_4.8, GND_4.9, GND_4.10, GND_4.11, GND_4.12, GND_4.13, GND_4.14, GND_4.15, JP12.2, JP13.2, SIGNAL_3.2; also elsewhere on the board
IN1: RELAY_CONTROL.1; also elsewhere on the board
IN2: RELAY_CONTROL.3; also elsewhere on the board
IN3: RELAY_CONTROL.5; also elsewhere on the board
IN4: RELAY_CONTROL.7; also elsewhere on the board
IN5: RELAY_CONTROL.9; also elsewhere on the board
unnamed: VCC.1, VCC.2, VCC.3, VCC.4, VCC.5, VCC.6, VCC.7, VCC.8, VCC_3.1, VCC_3.2, VCC_3.3, VCC_3.4, VCC_3.5, VCC_3.6, VCC_3.7, VCC_3.8, VCC_3.9, VCC_3.10, VCC_3.11, VCC_3.12, VCC_3.13, VCC_3.14, VCC_3.15, VCC_4.1, VCC_4.2, VCC_4.3, VCC_4.4, VCC_4.5, VCC_4.6, VCC_4.7, VCC_4.8, VCC_4.9, VCC_4.10, VCC_4.11, VCC_4.12, VCC_4.13, VCC_4.14, VCC_4.15, VCC_SELECT.2
VCC/2: VIN.1, VIN.2, VIN.3, VIN.4, VIN.5, VIN.6, VIN.7, VIN.8; also elsewhere on the board

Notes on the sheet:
PIN HEADER AND ESP32
JUARENDRA R.
PIN HEADER
ESP32

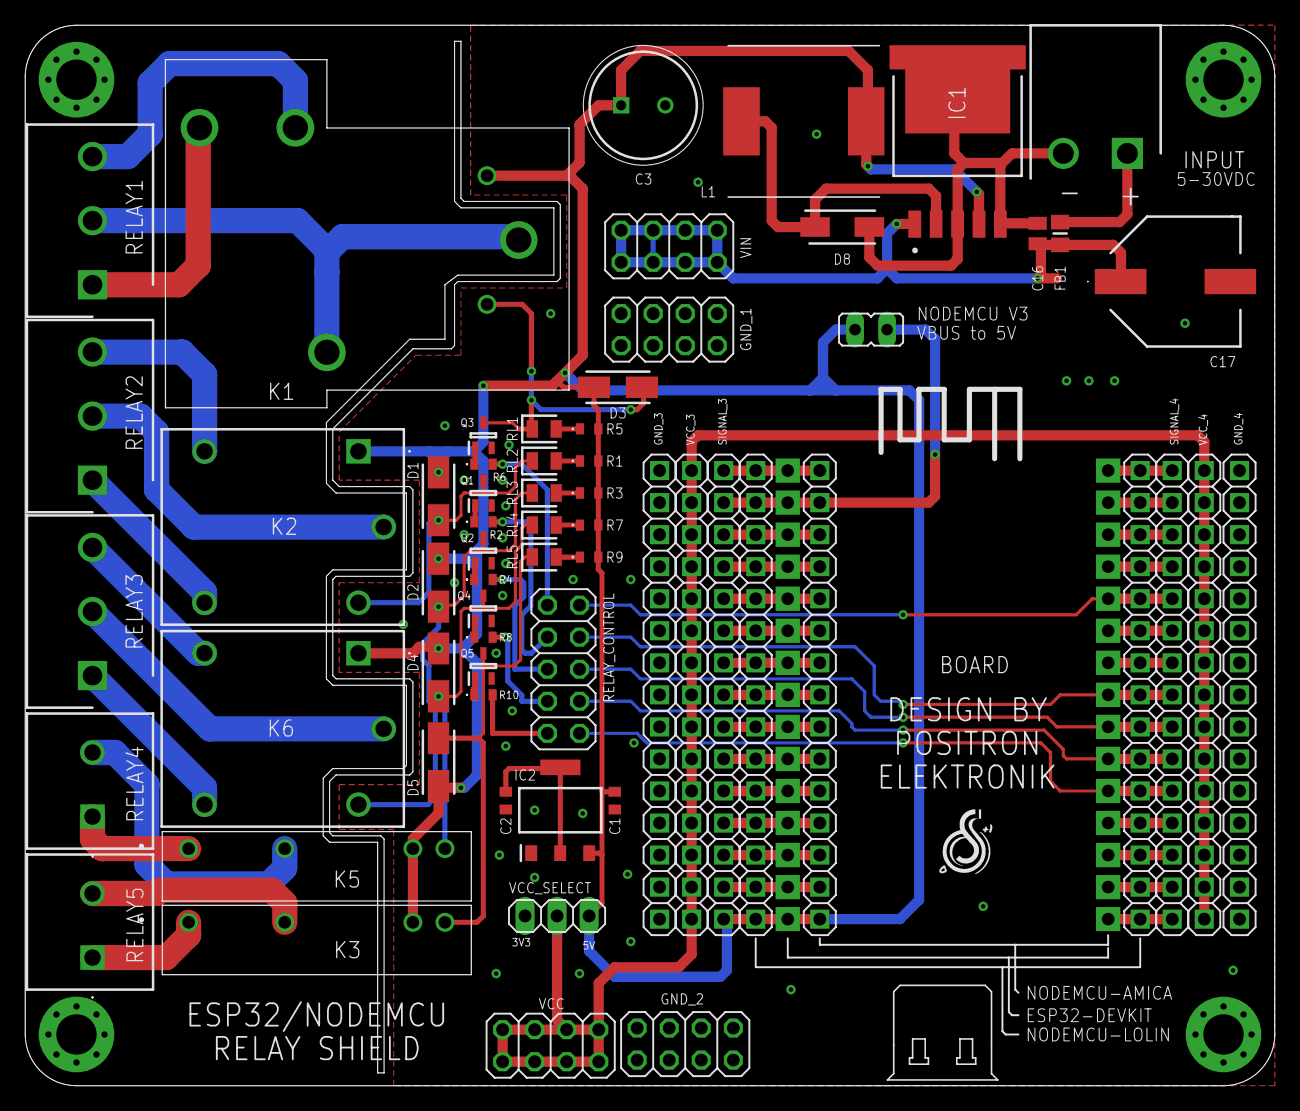
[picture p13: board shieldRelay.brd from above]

Board: 2 copper layers, 99.1 x 84.1 mm, 67 parts (1 on the bottom side), 68 nets.

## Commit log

2024-05-20 FEAT: add first pcb
    [shieldRelay.brd, shieldRelay.sch]
2024-05-22 FEAT: update library esp32 and remove nodemcu v2
    [shieldRelay.brd, shieldRelay.sch]
2024-05-22 FEAT: Positioning component
    [shieldRelay.brd, shieldRelay.sch]
2024-05-23 FEAT: update library pinhead
    [shieldRelay.brd, shieldRelay.sch]
2024-05-23 FEAT: update library esp32-dev
    [shieldRelay.brd, shieldRelay.sch]
2024-05-24 FEAT: update schematic
    [shieldRelay.brd, shieldRelay.sch]
2024-05-24 FEAT: add 3v3 regulator
    [shieldRelay.brd, shieldRelay.sch]
2024-05-24 FEAT: update board
    [shieldRelay.brd, shieldRelay.sch]
2024-05-24 FEAT: update terminal block
    [shieldRelay.brd, shieldRelay.sch]
2024-05-25 DOC: UPDATE SCHEMATIC, BOARD AND ADD PDF
    [shieldRelay.brd, shieldRelay.sch]
2024-05-26 FEAT: add 3D model
    [shieldRelay.brd, shieldRelay.sch]
2024-05-26 FEAT: add gerber file
    [shieldRelay.brd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]
2024-05-27 FEAT: Add plate
    [shieldRelayPlate.stl]
2024-05-28 DOC: add BOM
    [BOM_shieldRelay.csv]
2024-05-31 FEAT: add 5VDC to VBUS Jumper
    [copper_bottom.gbr, copper_top.gbr, drill_1_16.xln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]
2024-06-14 FIX: fix relay not connected to pin esp32
    [shieldRelay.brd, shieldRelay.sch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]
2024-06-18 FIX: fix gnd pin on ic 1117 that no connected and placing name diode feedback relay
    [copper_bottom.gbr, copper_top.gbr, drill_1_16.xln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]
2024-07-19 FIX: fix reverse transistor relay
    [shieldRelay.brd, shieldRelay.sch]
